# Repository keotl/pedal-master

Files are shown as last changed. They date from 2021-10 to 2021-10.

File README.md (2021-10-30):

# Pedal Master
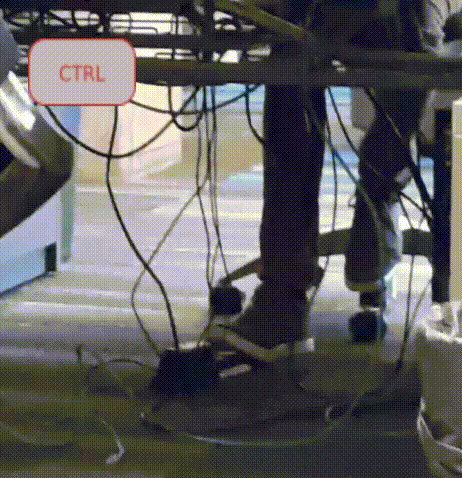
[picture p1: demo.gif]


A feet operated micro-keyboard design. Now, you can use digital
piano/synthesizer pedals to control your keyboard!

Compatible with digital piano pedals with a 1/4" connector
([example](example-pedal.jpg)), inverted and standard. See [the
buildguide](buildguide/buildguide-rev2.md) for more details.

## Motivation
The primary use-case for this is to use pedals to hold modifier keys
such as CTRL, SHIFT and ALT while operating an ordinary keyboard
normally.
For an in-depth explanation of the motivation behind this project, see
[this page](motivation.jpg).

See the
[blogpost](https://ligature.ca/the%20lab/2021/10/29/Writing-code-using-a-foot-pedal.html)
for an overview of the design process.

# Rev2
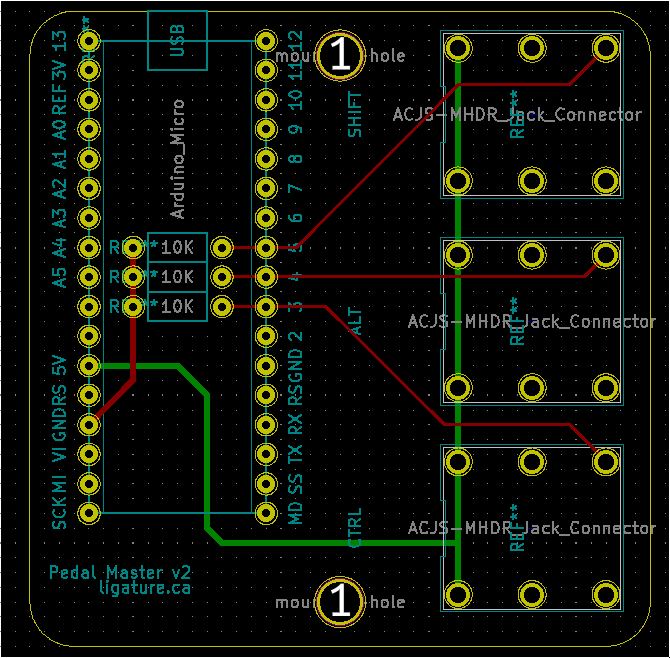
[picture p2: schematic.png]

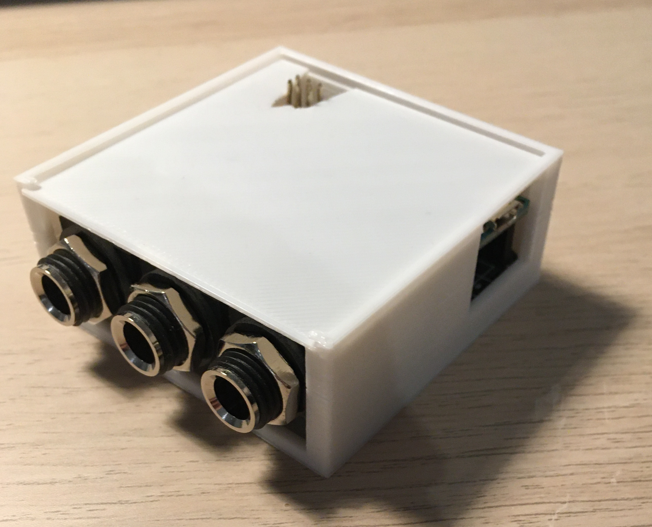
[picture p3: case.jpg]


The latest revision of the Pedal Master is the rev2. See [the buildguide](buildguide/buildguide-rev2.md).
Fabrication files for the PCB and the case are available in this repository.

# Enquiries
Contact me on Github for any enquiries.

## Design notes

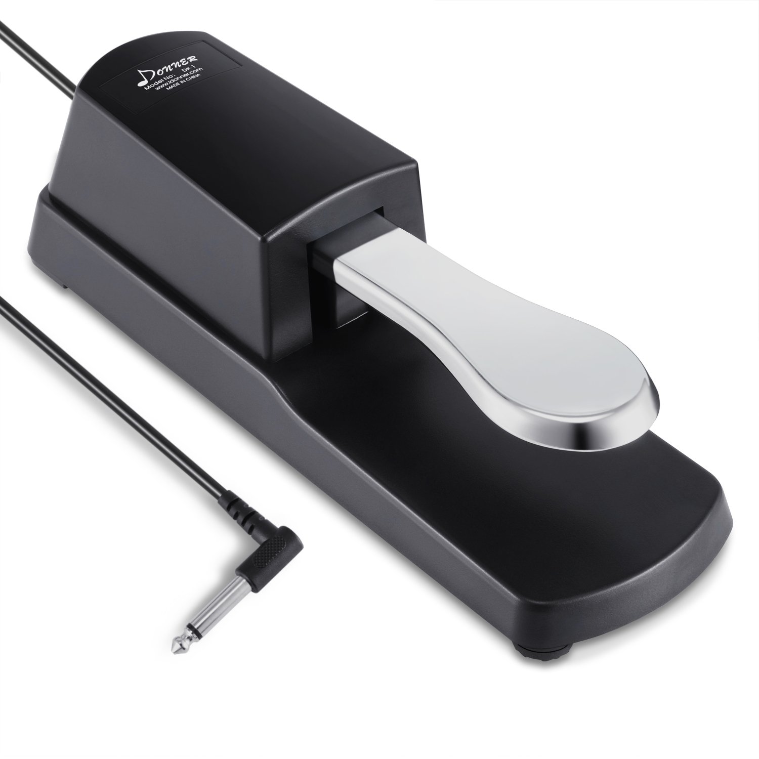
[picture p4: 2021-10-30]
example-pedal.jpg

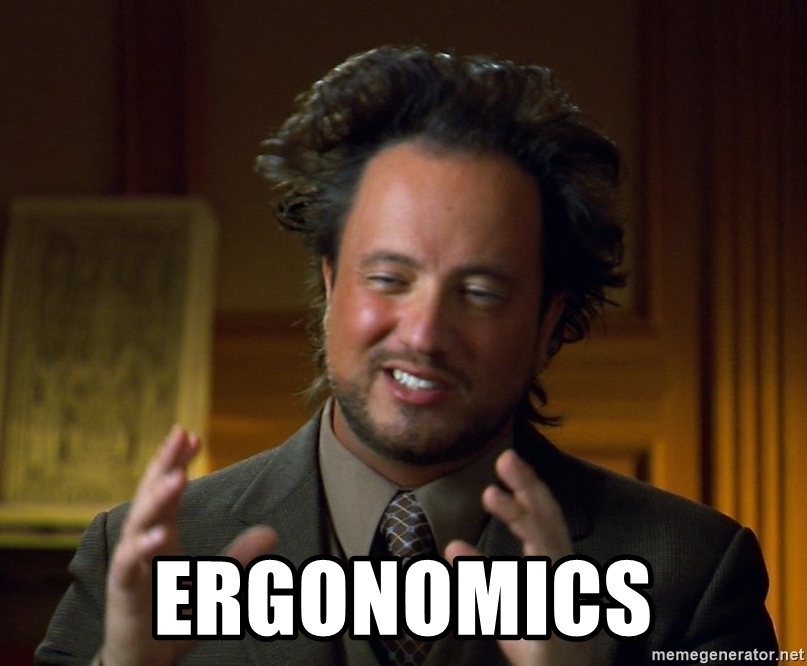
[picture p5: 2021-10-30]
motivation.jpg

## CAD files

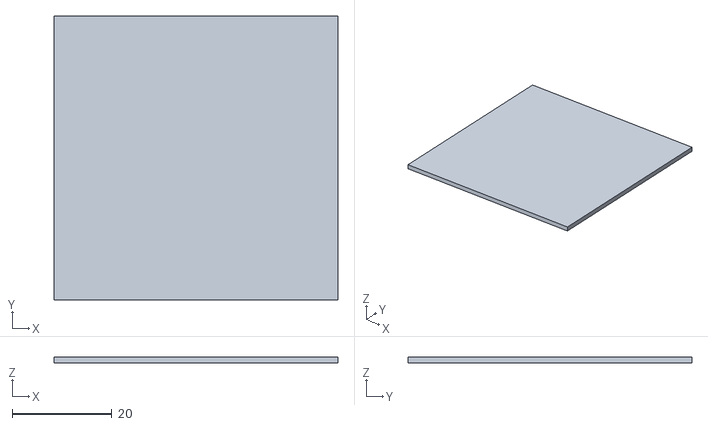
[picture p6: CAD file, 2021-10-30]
case/pedal lid.stl
56.8 x 56.8 x 1.30

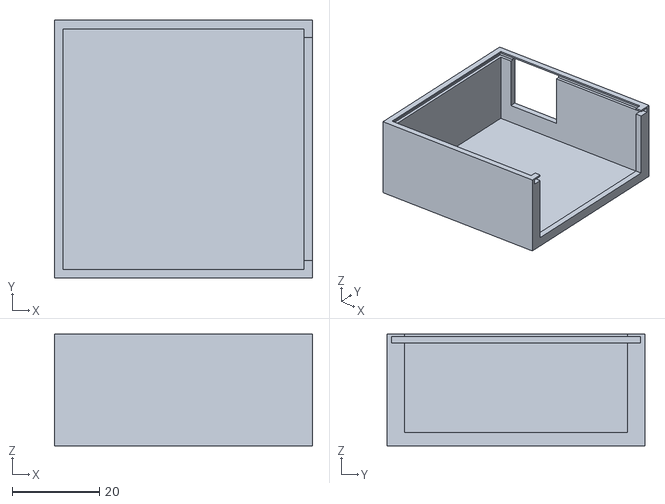
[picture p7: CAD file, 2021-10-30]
case/pedal case v2.stl
59.0 x 59.0 x 25.5

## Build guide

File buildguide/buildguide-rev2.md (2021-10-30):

# Build guide

## Parts required
- 1 Pedal master rev2 board
- 3 Amphenol audio 1/4" jack connectors ACJS/ACJM family.
    - Tested with [ACJS-MHDR](https://www.digikey.ca/en/products/detail/amphenol-sine-systems-corp/ACJS-MHDR/7105422)
- 3 10K resistors
- 1 Arduino Micro
- (Recommended) Male-female pin headers for mounting the arduino to the
  PCB. (Standard breadboard sizing.)

## Tools required
- Soldering iron

## Instructions
1. Solder the components to the PCB on the silkscreened side.
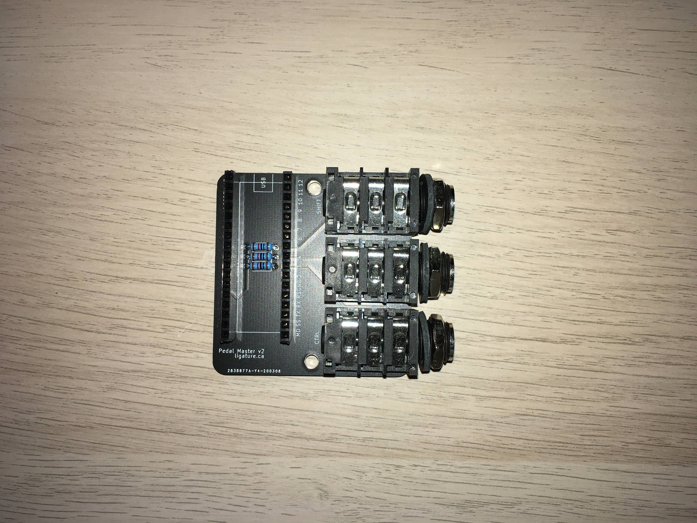
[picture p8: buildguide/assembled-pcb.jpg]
Assembled PCB


2. Edit the firmware file `firmware_rev2.ino` using the Arduino IDE
   and in the config section, set the `INVERTED` config variable to
   true if using inverted pedals. (e.g. Yamaha branded ones.)
   You can also edit what each pedal does by customizing the `KEYS`
   variable. Refer to `Keyboard.h` in the Arduino SDK for available keycodes.

3. Flash the firmware to your Arduino micro.

4. Enjoy your new foot-operated keyboard! Note that no driver is
   required for usage, since the Arduino emulates a standard USB keyboard.

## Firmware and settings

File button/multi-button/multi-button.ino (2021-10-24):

#include <Keyboard.h>

const int BUTTONS[3] = {3,4,5};
const int KEYS[3] = {KEY_LEFT_CTRL, KEY_LEFT_ALT, KEY_LEFT_SHIFT};
const bool INVERTED[3] = {true,false,false};

int buttonStates[3] = {0,0,0};
bool keyboardStates[3] = {false, false, false};


void incrementState(int i) {
  if (buttonStates[i] < 10) {
    buttonStates[i]++;
  }
}

void decrementState(int i) {
  if (buttonStates[i] > 0) {
    buttonStates[i]--;
  }
}

void readButton(int i) {
  if (digitalRead(BUTTONS[i]) == HIGH) {
    if (INVERTED[i]) {
      decrementState(i);
    } else {
      incrementState(i);
    }
  } else {
    if (INVERTED[i]) {
      incrementState(i);
    }
    else {
      decrementState(i);
    }
  }
}

void updateKeyboard() {
  for (int i = 0; i < 3; i++) {
    if (buttonStates[i] >= 5 && !keyboardStates[i]) {
      keyboardStates[i] = true;
      Keyboard.press(KEYS[i]);
    } else if (buttonStates[i] < 5 && keyboardStates[i]) {
      keyboardStates[i] = false;
      Keyboard.release(KEYS[i]);
    }
  }
}

void setup() {
  Keyboard.begin();
  for (int i = 0; i < 3; i++) {
    pinMode(BUTTONS[i],INPUT);
  }
}

void loop() {
  for (int i = 0; i < 3; i++) {
    readButton(i);
  }
  updateKeyboard();
  delay(5);
}

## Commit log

2019-11-30 PCB WIP
    [pedal-controller.kicad_pcb, pedal-controller.sch]
2019-11-30 ordered version
    [pedal-controller-B_Cu.gbr, pedal-controller-B_Mask.gbr, pedal-controller-B_Paste.gbr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]
2019-12-02 ordered version 2
    [pedal-controller-B_Cu.gbr, pedal-controller-B_Mask.gbr, pedal-controller-B_Paste.gbr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]
2019-12-08 Multi-button controller
2020-03-07 ordered version 3
    [pedal-controller-B_Cu.gbr, pedal-controller-B_Mask.gbr, pedal-controller-B_Paste.gbr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]
2020-05-10 move buttons
2021-10-24 inverted button logic
2021-10-24 directory cleanup rev2
    [pedal-controller-B_Cu.gbr, pedal-controller-B_Mask.gbr, pedal-controller-B_Paste.gbr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]
